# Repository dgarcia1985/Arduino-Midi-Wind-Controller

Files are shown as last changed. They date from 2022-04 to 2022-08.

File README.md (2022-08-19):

# Controlador de viento Midi   
<a href="README.en.md">English</a>   

<a href="https://www.youtube.com/watch?v=sx2wOH4ftkw">Vídeo de demostración</a>   

Aquí está el <a href="Code/midiWindController.ino">código</a> y los recursos para construir un controlador de viento Midi basado en Arduino.   
Mi objetivo era construir un controlador barato con una dinámica mejor que un teclado para tocar trompetas, saxofones, flautas y otros instrumentos de viento.   
He montado el prototipo con piezas impresas en 3D (Los archivos están Disponibles en la carpeta Parts), piezas desmontadas de mandos de videojuegos rotos, cables de distintos dispositivos USB estropeados, sensores y botones.

Las características del instrumento son las siguientes:

* 12 botones para seleccionar que nota se va a tocar, pueden accionarse de forma simultánea.  
* 1 sensor de presión GY-68 BMP180.   
* 1 Joystick de un mando viejo de GameCube para controlar la rueda de Pitch/Modulación.
* 1 potenciómetro lineal del gatillo de un mando de GameCube para controlar el ataque mordiendo la boquilla.
* 8 botones que permiten cambiar configuraciones del dispositivo y calibrarlo.   

Abajo podemos ver el esquema de conexiones del dispositivo:

esquema  

Para poder utilizarlo como un dispositivo MIDI USB normal es necesario reprogramar el firmware de Arduino con <a target="_blank" href="https://github.com/ddiakopoulos/hiduino">Hiduino</a> o similar.   
Para realizar pruebas hasta reprogramar la placa de Arduino como dispositivo MIDI he utilizado <a target="_blank" href="https://projectgus.github.io/hairless-midiserial/">Hairless Midi</a>, ten en cuenta que la tasa de Baudios del dispositivo MIDI es distinta si lo utilizamos con esta aplicación. Se detallará en las instrucciones de montaje.   
Las piezas 3D están modeladas con <a target="_blank" href="https://www.freecadweb.org/">FreeCAD</a>   
Muchas de las piezas utilizadas son demasiado grandes para mi impresora 3D, por lo que algunas piezas han sido impresas partidas en dos para luego unirlas, algunas piezas van atornilladas pero otras han sido unidas utilizando un soldador para fundir el plástico.   
He impreso las piezas en PETG, pero casi todas las piezas deberían poder hacerse en cualquier plástico. La lengüeta que transmite la fuerza de mordida debería estar impresa en un plástico bastante resistente (ABS o PETG).   

Los planos de las piezas los puedes consultar <a href="Plano.pdf">aquí</a>.

También tienes disponibles <a href="Parts/Stl">las Piezas para imprimir en formato stl</a> y <a href="Parts/FreeCAD">las piezas modeladas en FreeCAD por si quieres realizar alguna modificación.</a>   

La lista completa de componentes es la siguiente:

* Placa Arduino Uno o compatible (Asegurate de que puede reprogramarse o sólo lo podrás usar mediante un programa Serial a Midi).   
* 12 Botones de interruptor para Arduino.   
* 1 Joystick (Sólo utilizaremos un eje así que puede valer cualquier potenciómetro rotatorio con un sistema de retorno a la posición central).   
* 1 potenciómetro deslizante (Utilice el de el gatillo de un mando de GameCube, pero se estropeó y lo cambié por uno A20K que es lo que encontré que me entrará en la pieza que ya tenía diseñada) que recibirá la fuerza de la mordida.
* 1 Muelle para crear el efecto de autoretorno en el potenciómetro deslizante (También utilice uno de un mando de GameCube roto).
* 4 resistencias de 1k, 2 de 2k, 2 de 5.1k y 2 de 10k. Los valores en realidad pueden ser distintos. En la wiki con las instrucciones de montaje hay más información sobre lo que hacen.   
* 1 sensor GY-68 BMP180.
* Conectores JST para organizar los cables de manera más sencilla.
* Las Piezas impresas en 3D de arriba.

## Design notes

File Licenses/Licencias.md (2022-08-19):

# Licencias

Este repositorio no distribuye código de terceros aunque para compilarlo tendrás que descargar del gestor de librerías de Arduino IDE las siguientes librerías:

* [MIDI Library](https://www.arduino.cc/reference/en/libraries/midi-library/)
* [Adafruit Bmp 085](https://www.arduino.cc/reference/en/libraries/adafruit-bmp085-library/)

# Imágenes

Para las instrucciones de la wiki he sacado imágenes de las siguientes fuentes:
* [Placa Arduino UNO](https://commons.wikimedia.org/wiki/File:ArduinoUno.svg)
* [Botones (Están modificados)](https://elements.wokwi.com/?path=/story/pushbutton--red)
* [Resistencias](https://elements.wokwi.com/?path=/story/resistor--1%CF%89)
* [Joystick](https://elements.wokwi.com/?path=/story/analog-joystick--joystick)
* [Potenciómetro deslizante](https://elements.wokwi.com/?path=/story/slide-potentiometer--default)

# Software utilizado

Para realizar tanto el proyecto como la documentación he usado los siguientes programas:

* [Arduino IDE](https://www.arduino.cc/en/software) 
* [FreeCAD para el modelado de piezas y los planos](https://www.freecad.org/downloads.php)
* [Blender para los vídeos de montaje e imágenes de la documentación](https://www.blender.org/)
* [Inkscape para los dibujos de la documentación](https://inkscape.org/es/)
* [QSynth para probar el instrumento en vídeos de prueba](https://qsynth.sourceforge.io/)

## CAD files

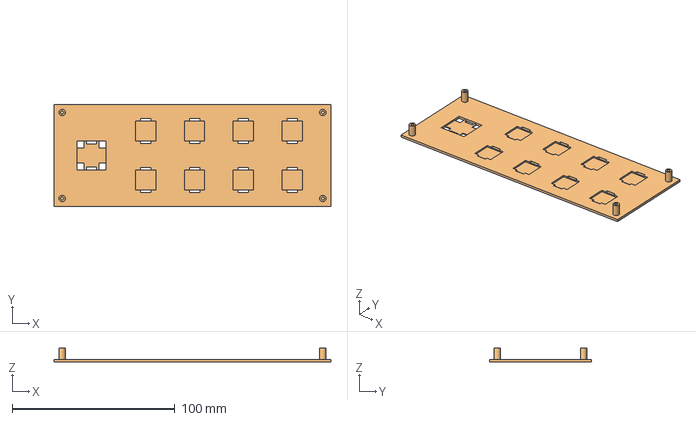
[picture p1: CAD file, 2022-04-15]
Parts/FreeCAD/soporte botones atras.FCStd
170.0 x 62.8 x 8.50 mm

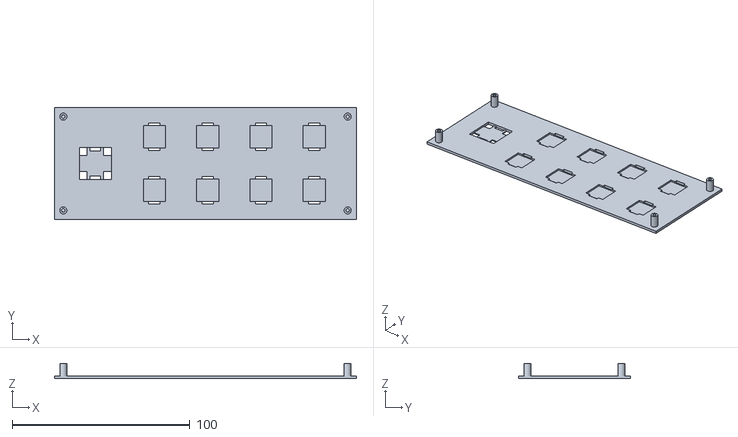
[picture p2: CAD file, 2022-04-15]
Parts/Stl/04 - Soporte de botones trasero.stl
170.0 x 62.8 x 8.50

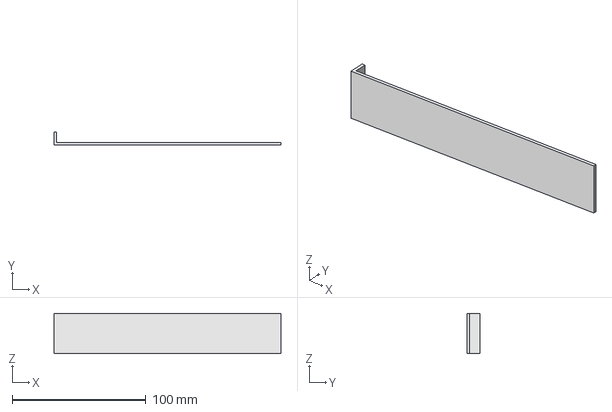
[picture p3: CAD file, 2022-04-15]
Parts/FreeCAD/tapa lados.FCStd
170.0 x 10.0 x 30.0 mm

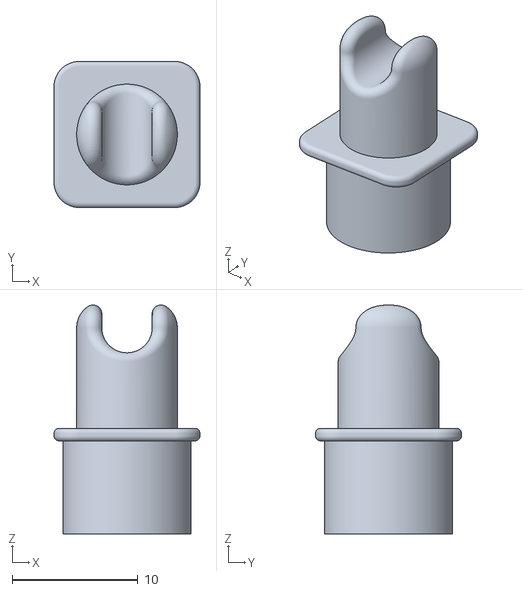
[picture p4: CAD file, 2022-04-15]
Parts/Stl/20 - Tapa potenciometro.stl
11.6 x 11.6 x 18.2

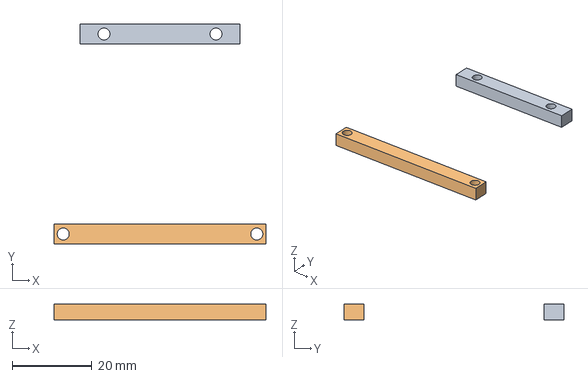
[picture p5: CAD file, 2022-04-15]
Parts/FreeCAD/Soportes tornillos.FCStd
53.0 x 55.0 x 4.00 mm
soporte tornillos arduino 1_Body_001
soporte tornillos arduino 2_Body_001

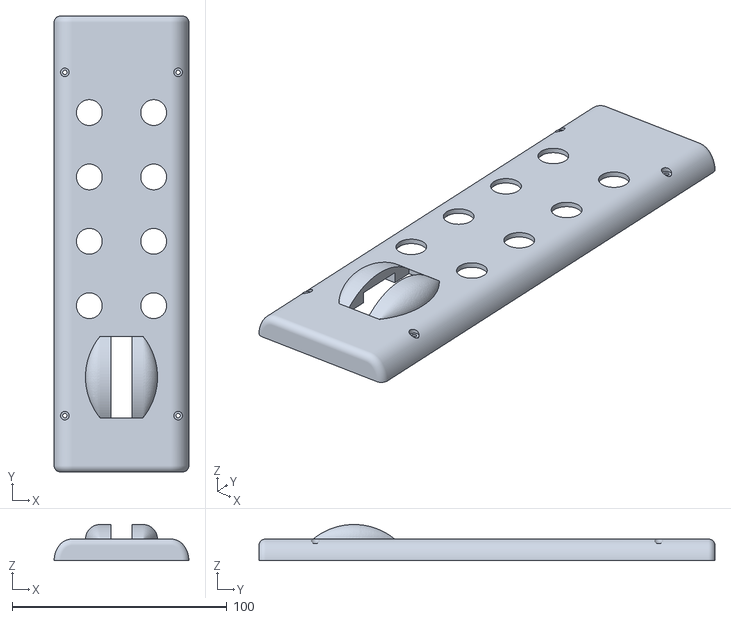
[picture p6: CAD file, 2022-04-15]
Parts/Stl/01 - Cubierta Trasera.stl
62.8 x 212.5 x 16.8

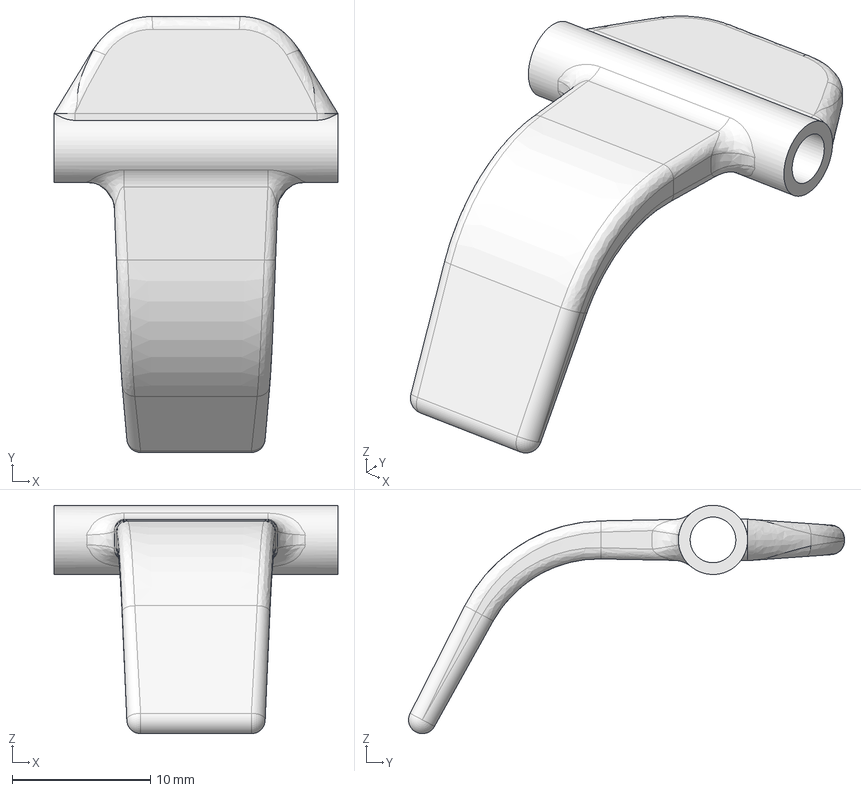
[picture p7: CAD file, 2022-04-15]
Parts/FreeCAD/lengueta.FCStd
20.5 x 31.5 x 16.5 mm

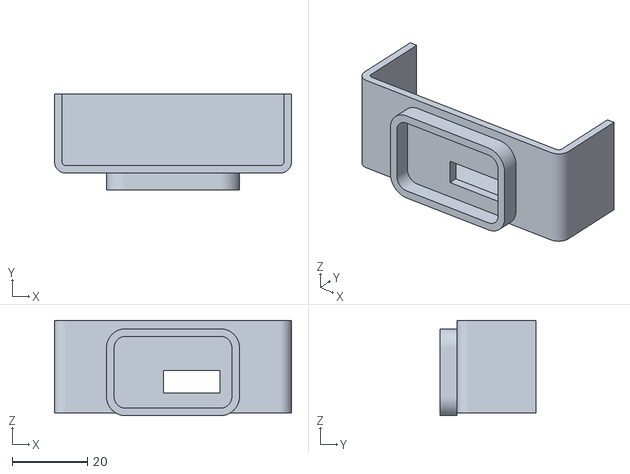
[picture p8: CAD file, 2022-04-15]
Parts/Stl/06 - Enganche Boquilla.stl
62.8 x 25.5 x 25.2

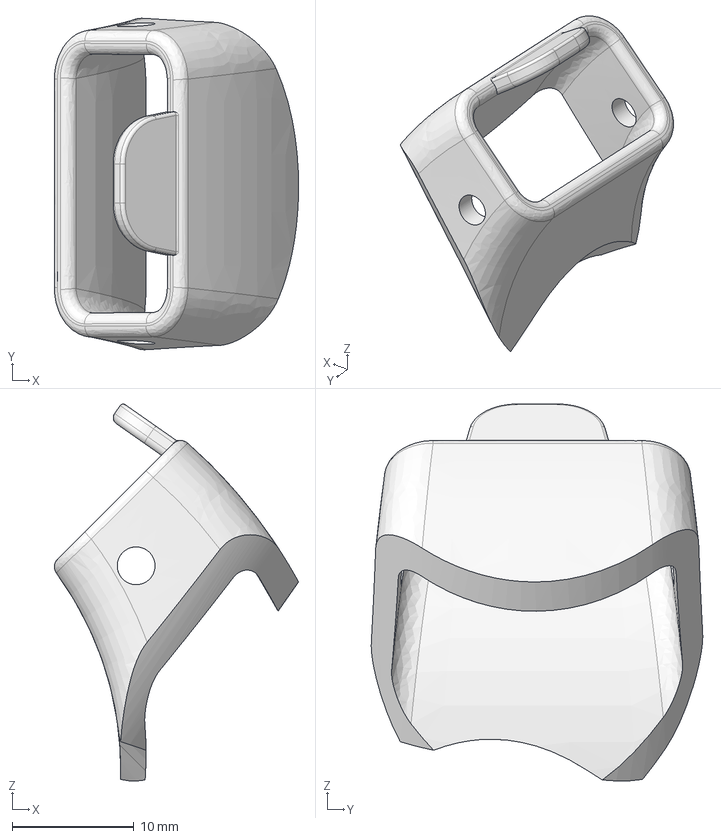
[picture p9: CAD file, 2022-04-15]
Parts/FreeCAD/boquilla.FCStd
20.0 x 27.2 x 30.9 mm

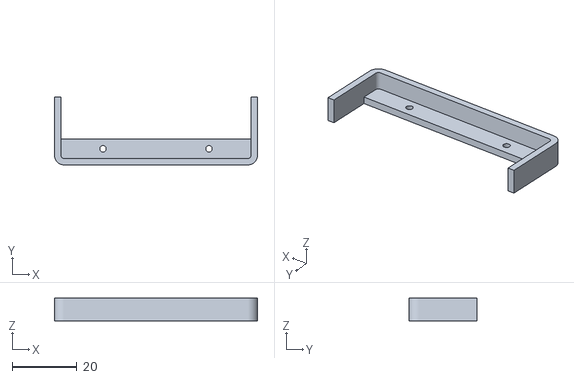
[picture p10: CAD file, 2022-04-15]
Parts/Stl/11 - Tapas.stl
62.8 x 21.0 x 7.00

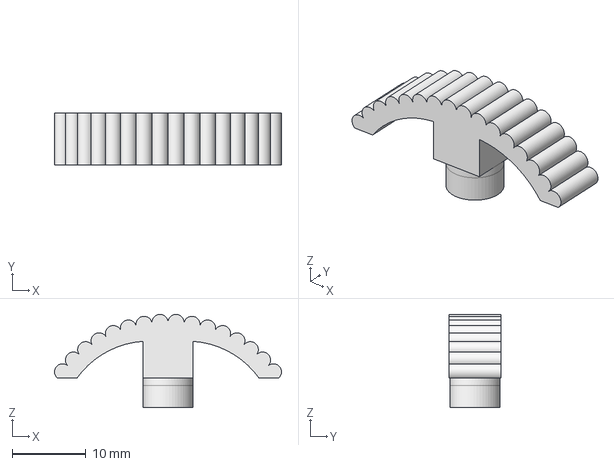
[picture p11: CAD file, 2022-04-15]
Parts/FreeCAD/rueda pitch.FCStd
30.8 x 7.00 x 12.7 mm

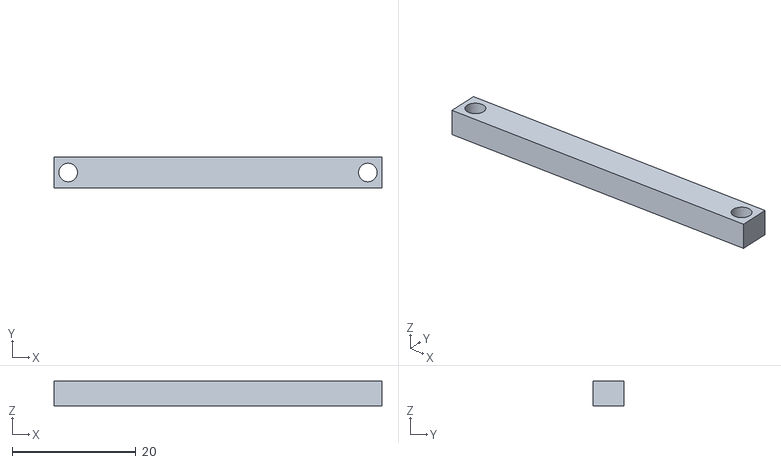
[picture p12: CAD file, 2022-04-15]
Parts/Stl/09 - Soporte tornillos arduino 2.stl
53.0 x 5.00 x 4.00

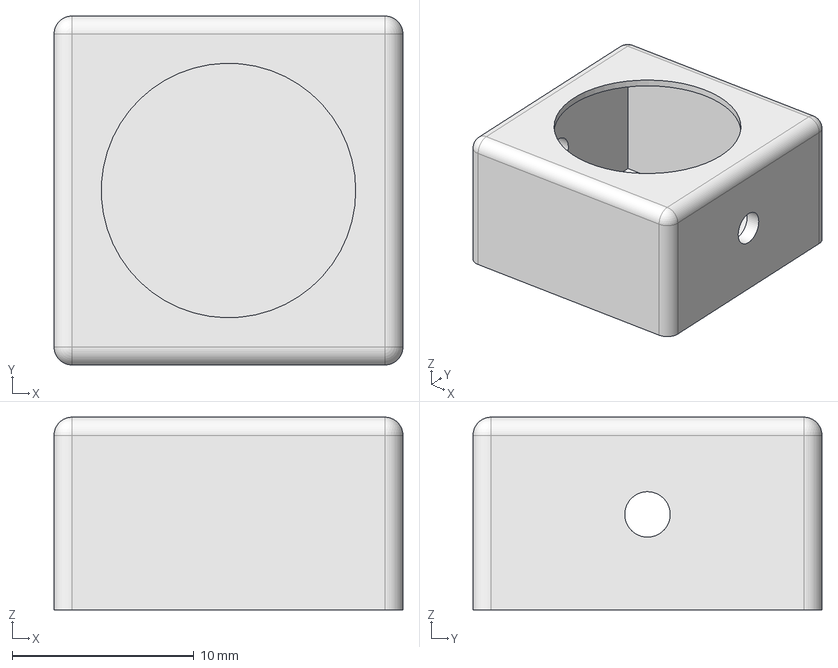
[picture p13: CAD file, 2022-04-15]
Parts/FreeCAD/Base Joystick.FCStd
19.2 x 19.2 x 10.6 mm

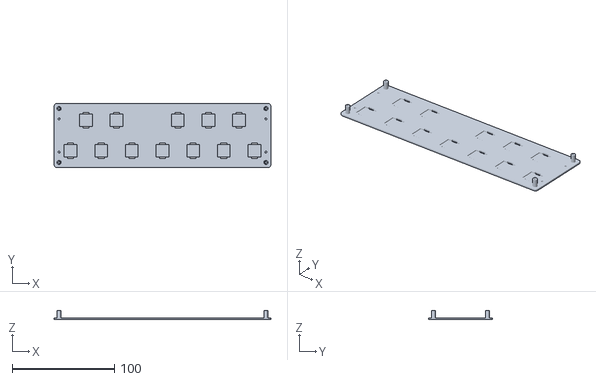
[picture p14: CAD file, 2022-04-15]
Parts/Stl/21 - Soporte botones arriba.stl
212.5 x 62.8 x 8.50

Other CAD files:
Parts/FreeCAD/Potenciometro.FCStd
Parts/Stl/14 - Lengueta.stl
Parts/FreeCAD/tapas.FCStd
Parts/Stl/05 - Rueda pitch.stl
Parts/FreeCAD/Arduino Uno.FCStd
Parts/FreeCAD/Base boton.FCStd
Parts/FreeCAD/Eje Joystick.FCStd
Parts/FreeCAD/Muelle.FCStd
Parts/FreeCAD/Pulsador Boton.FCStd
Parts/FreeCAD/carcasa arduino.FCStd
Parts/FreeCAD/carcasa pot linear.FCStd
Parts/FreeCAD/cubierta trasera.FCStd
Parts/FreeCAD/cubierta.FCStd
Parts/FreeCAD/eje.FCStd
Parts/FreeCAD/enganche boquilla.FCStd
Parts/FreeCAD/placa resistencias.FCStd
Parts/FreeCAD/soporte botones.FCStd
Parts/FreeCAD/soporte tornillos arduino 1.FCStd
Parts/FreeCAD/soporte tornillos arduino 2.FCStd
Parts/FreeCAD/tapa pot linear.FCStd
Parts/Stl/07 - Carcasa para Arduino.stl
Parts/Stl/08 - Soporte tornillos arduino 1.stl
Parts/Stl/12 - Tapa Lados.stl
Parts/Stl/13 - Boquilla.stl
Parts/Stl/17 - Carcasa Potenciometro.stl
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

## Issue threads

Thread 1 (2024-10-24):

Contacto

habuenav, 2024-10-24:
Hola, discúlpame que te contacte por acá, solo que veo que te interesan este tipo de proyectos y yo actualmente estoy  trabajando también en un EWI, lo mio es mas la programación que el diseño 3D y electrónico, entonces como necesito un poco de ayuda con ese tema, quería saber cuanto me cobrarías por ayudarme a diseñar la carcasa para mi proyecto, actualmente ya tengo un boceto muy básico hecho con tinkercad pero quisiera algo mejor y quizás tu puedas ayudarme con ese tema ya que veo que te interesan este tipo de proyectos, te comparto la presentación de mi proyecto en un grupo de makers https://www.youtube.com/watch?v=MsFFuOXiIuM&t=1822s  de antemano gracias por la atención prestada y muy buen trabajo con tu proyecto.

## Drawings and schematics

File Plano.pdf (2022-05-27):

# ControladordeViento MidiBasado en Arduino

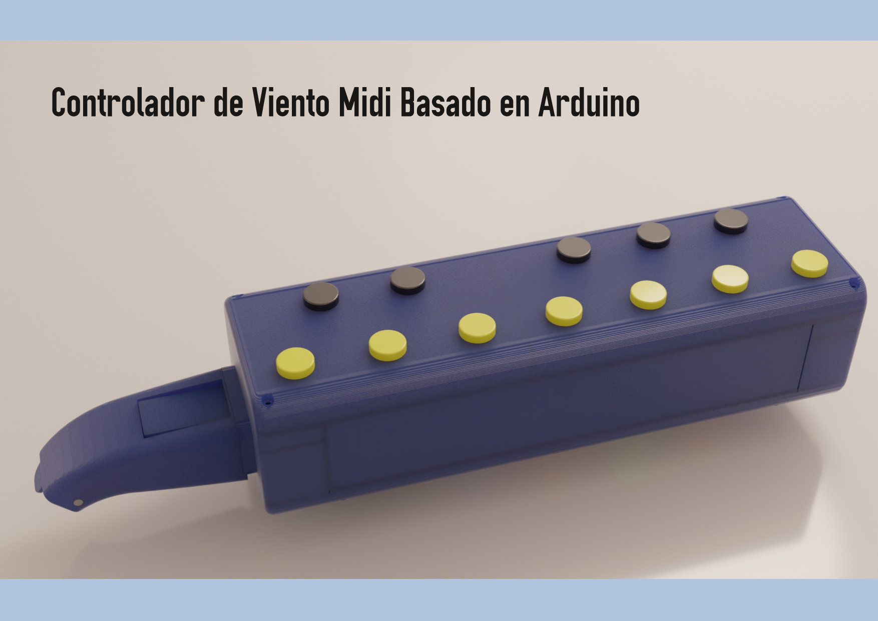
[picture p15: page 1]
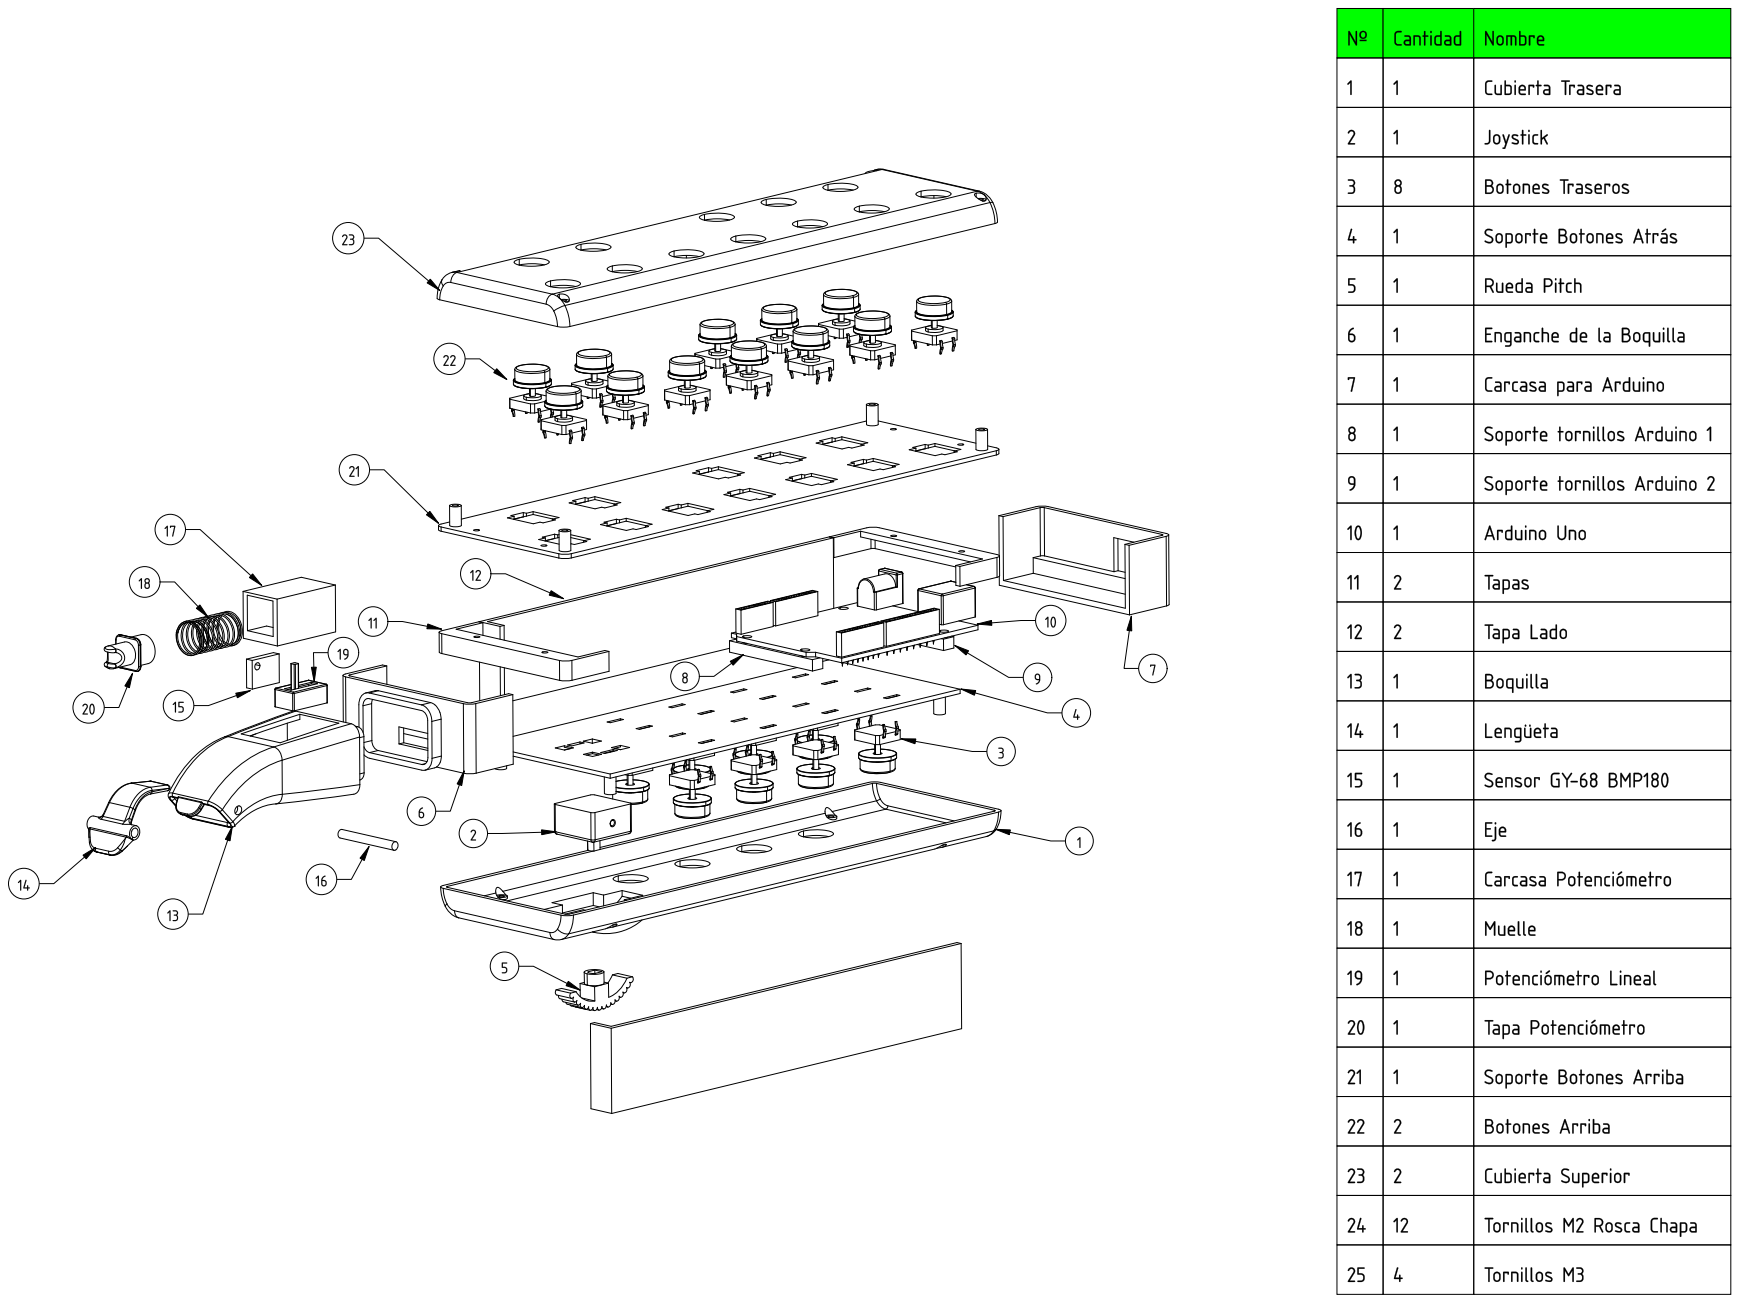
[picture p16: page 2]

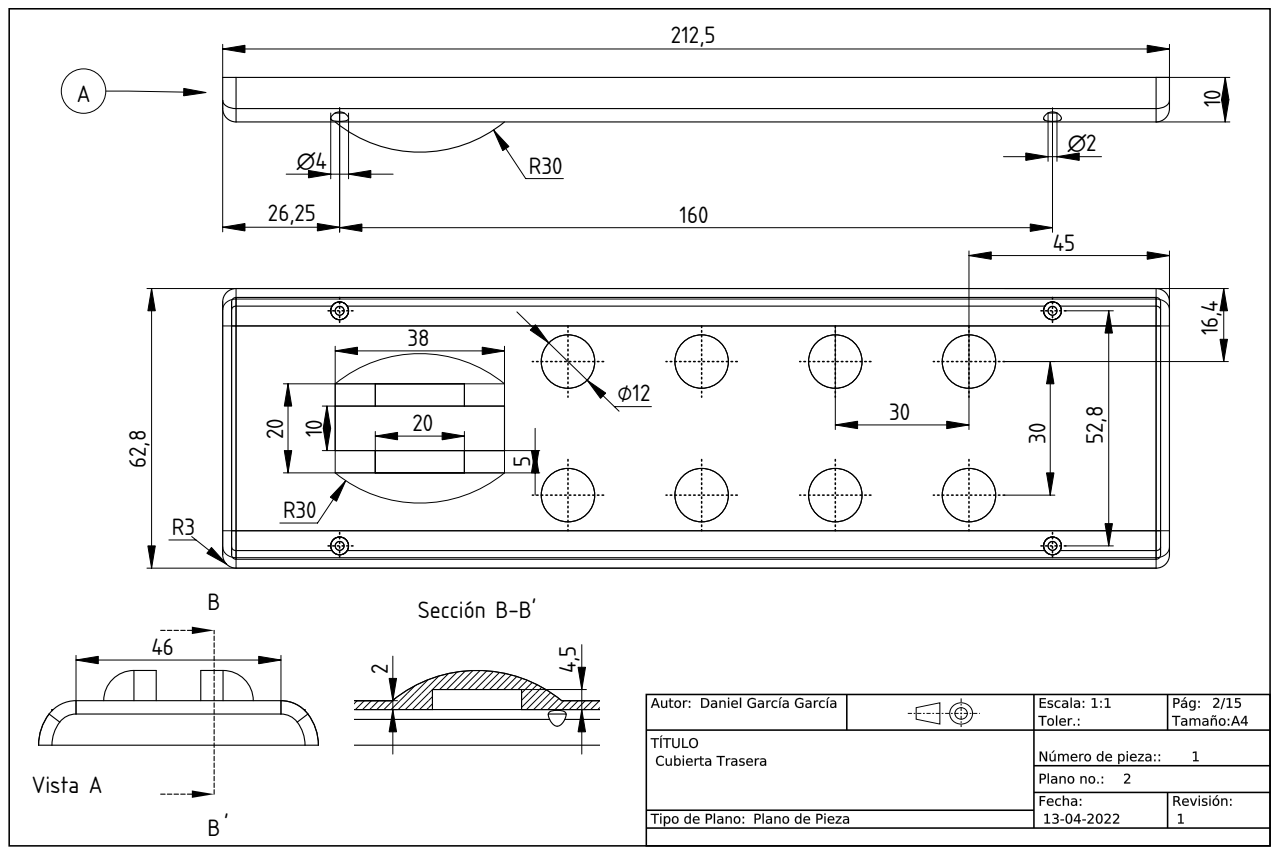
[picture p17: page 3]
Vista; ecció

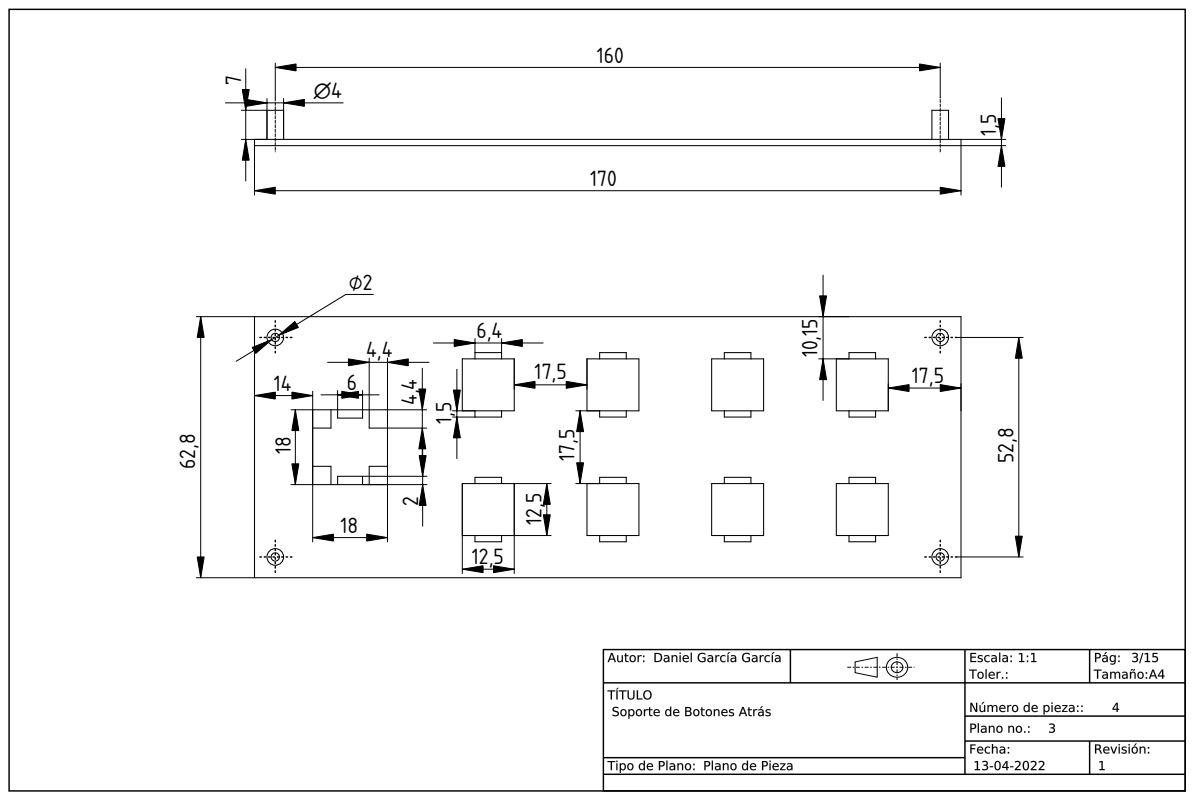
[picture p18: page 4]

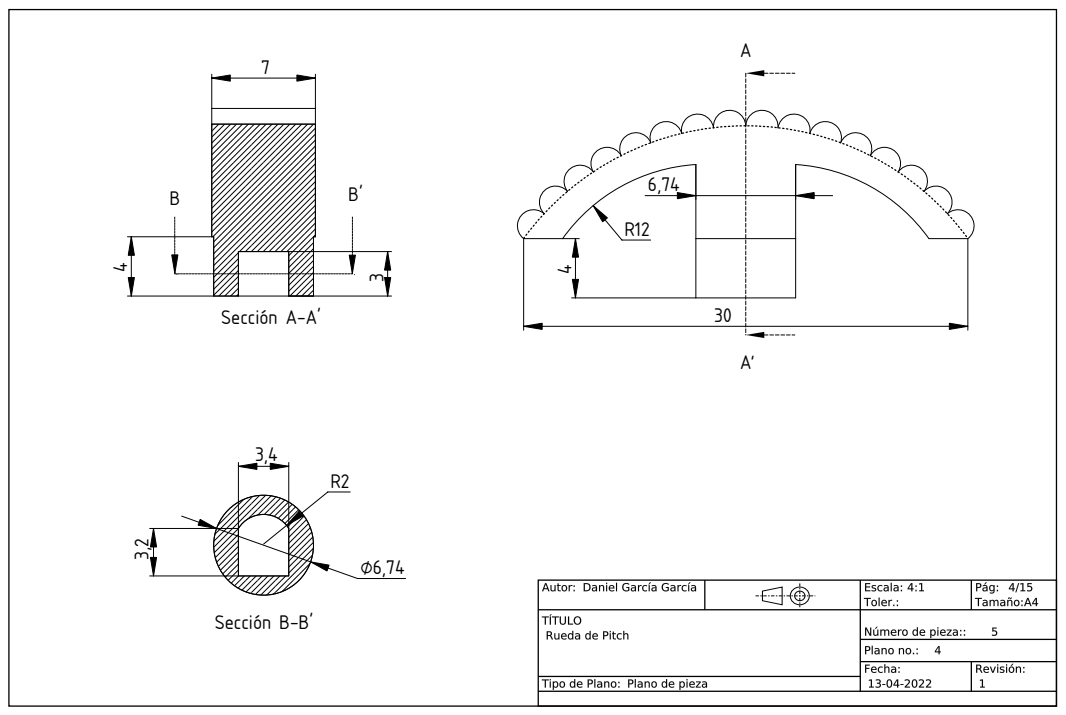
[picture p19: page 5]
Sección A-A'; Sección B-B'

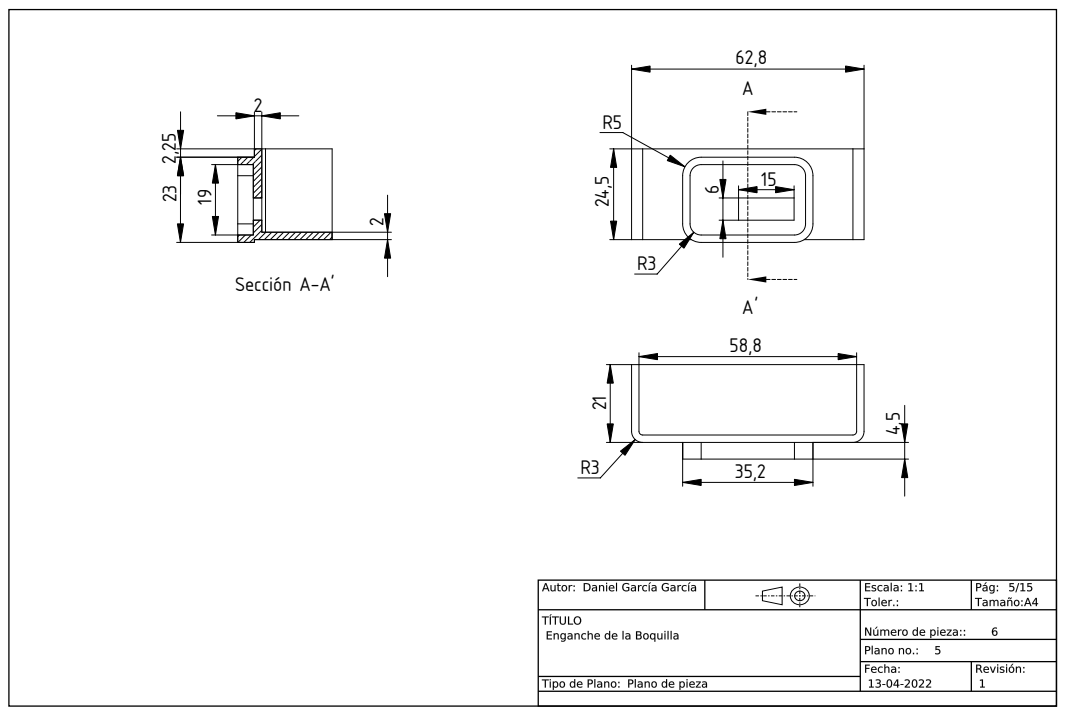
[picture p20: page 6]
ecció

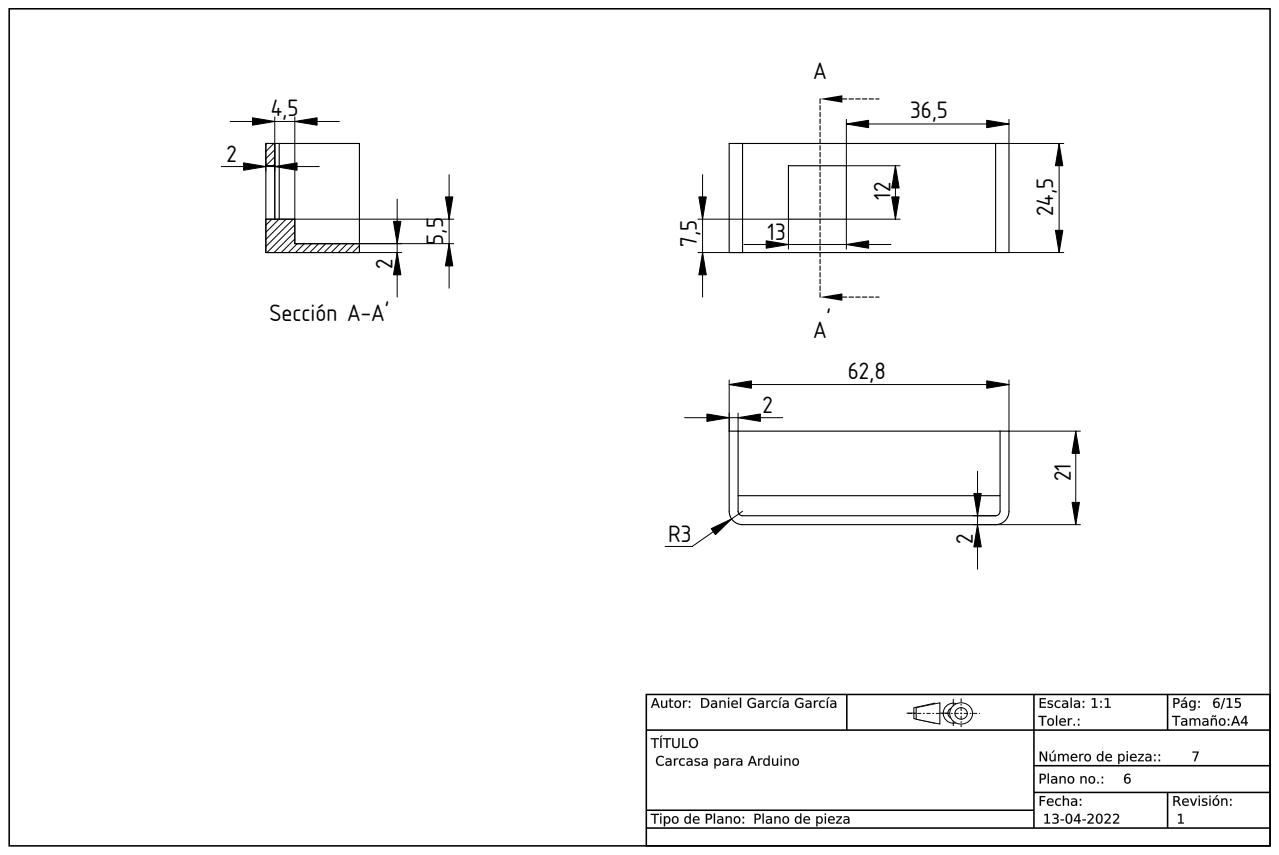
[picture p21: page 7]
ecció

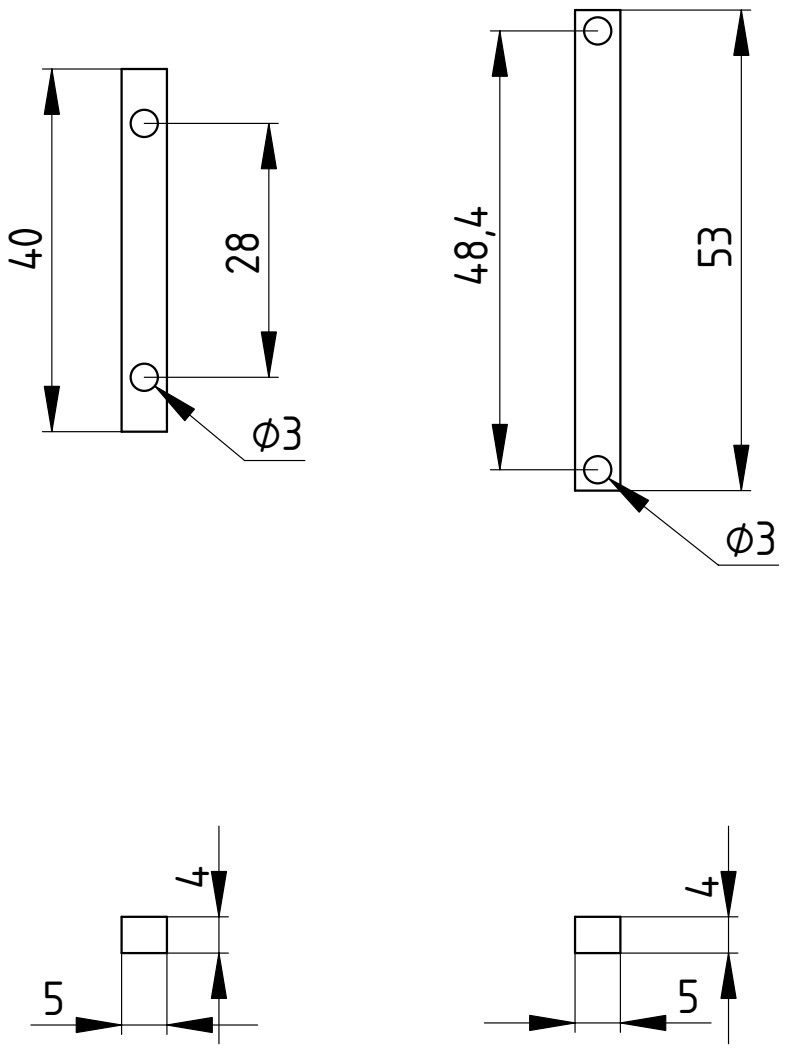
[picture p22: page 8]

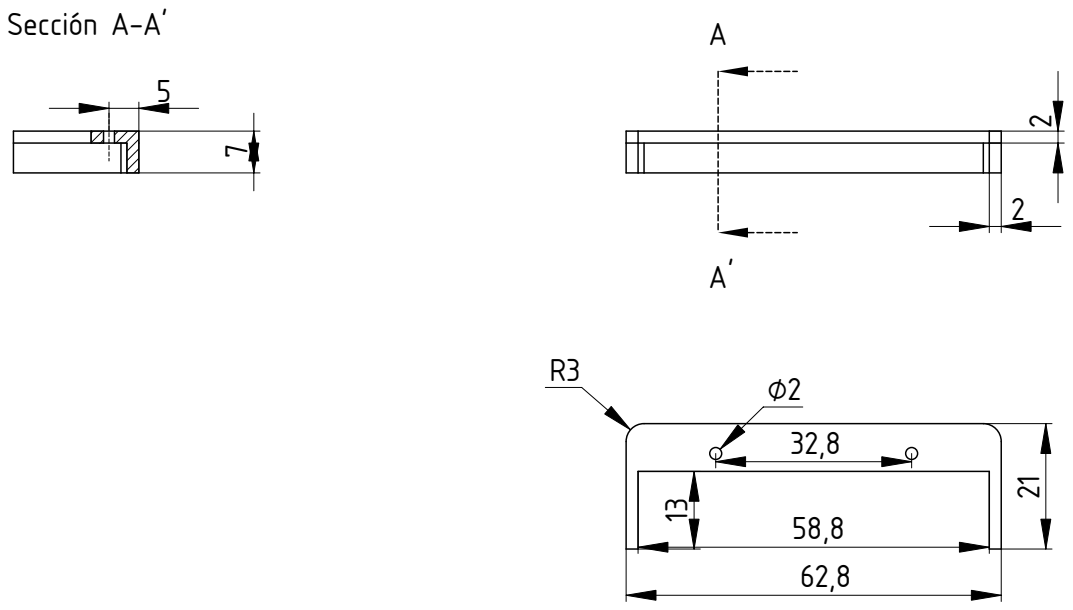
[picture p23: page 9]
ecció

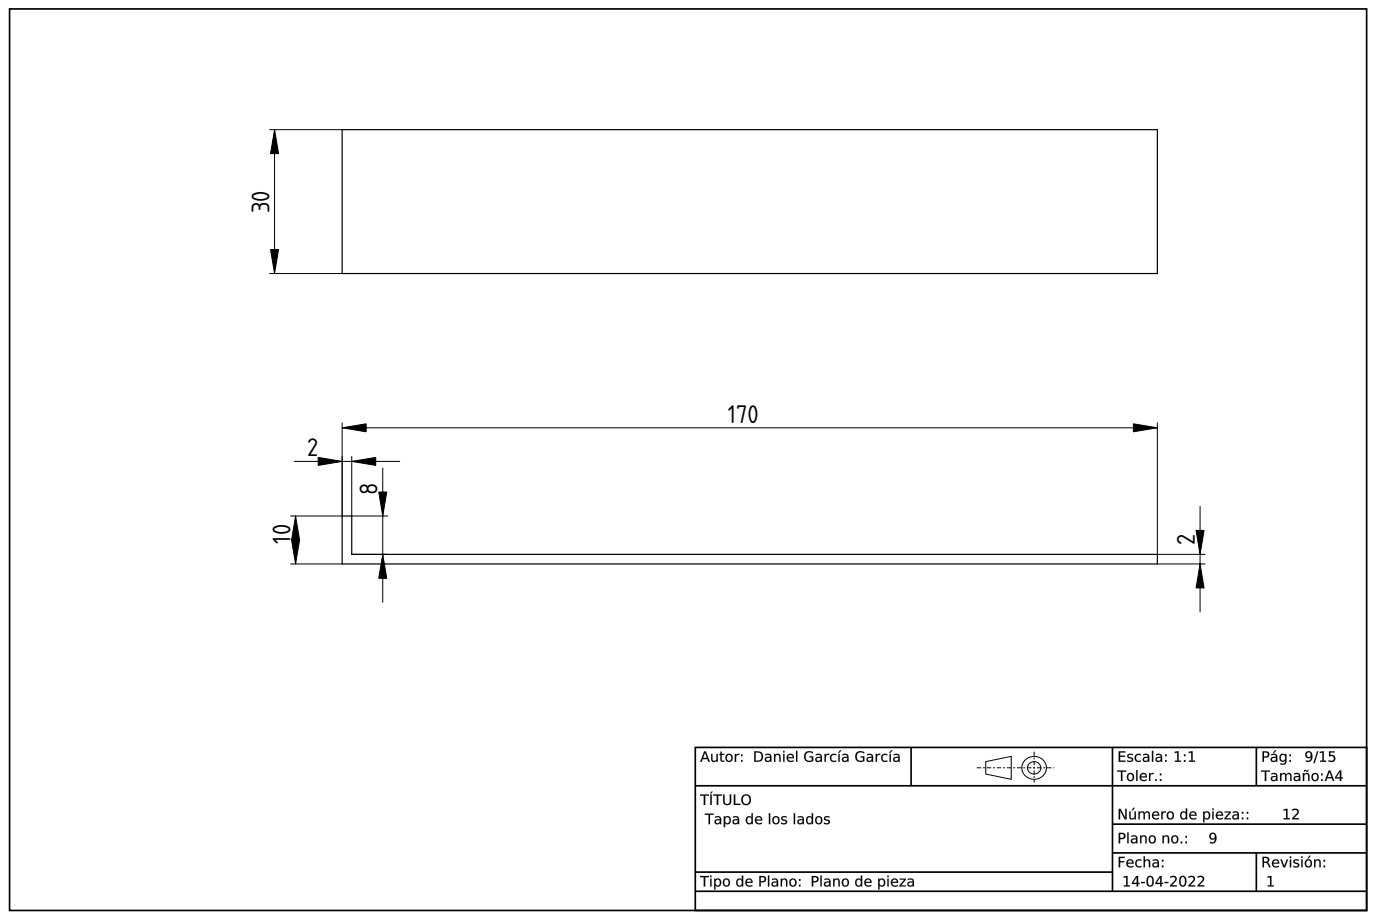
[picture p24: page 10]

3,1 R

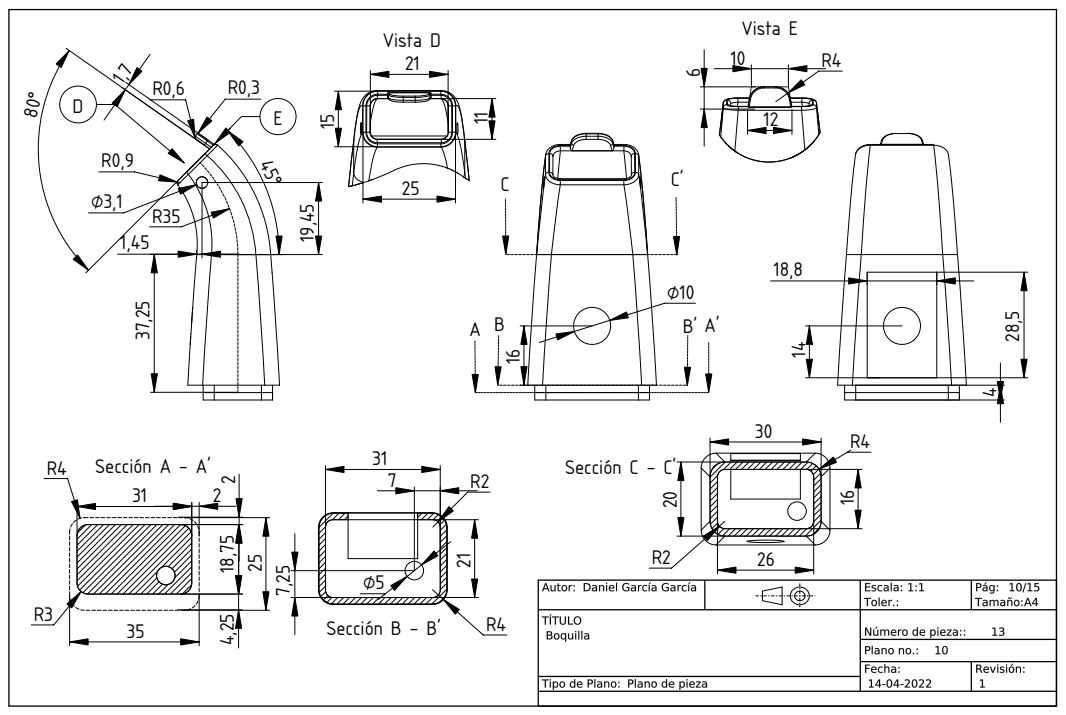
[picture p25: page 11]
ecció; C' Sección C - C' 25; Vista

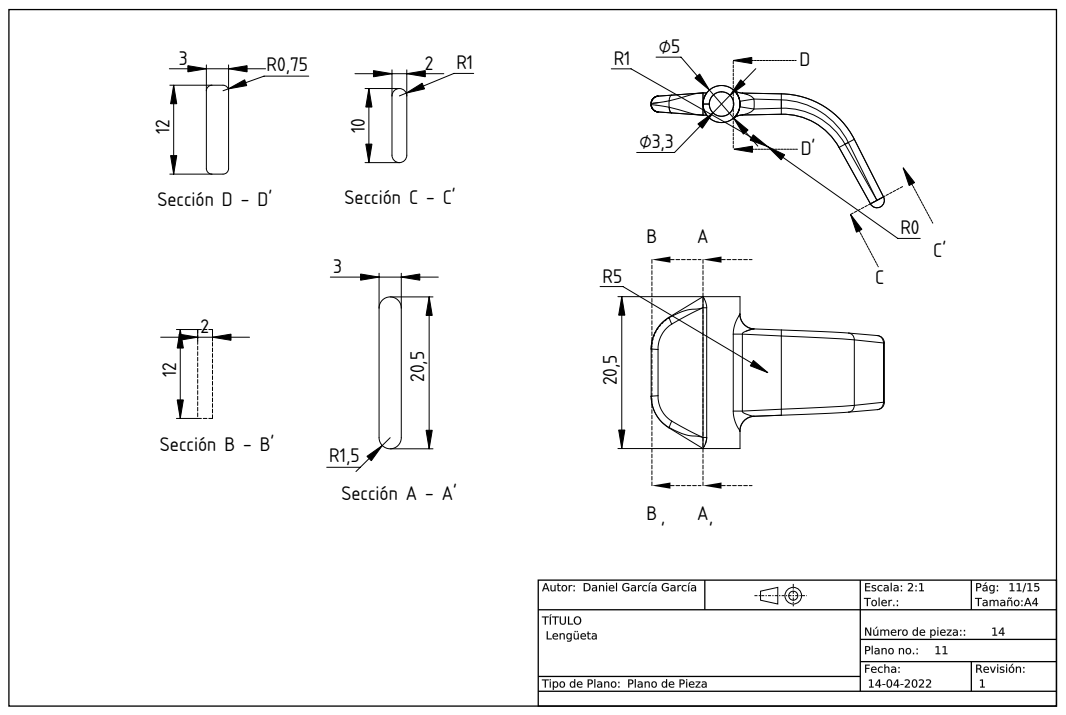
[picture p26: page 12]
ecció; R1 Sección D - D'; Sección C - C'


0,7 6

ecció


Sección A-A' Escala 1:2; Sección B - B'

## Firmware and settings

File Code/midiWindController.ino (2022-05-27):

#include <MIDI.h>
#include <Adafruit_BMP085.h>
MIDI_CREATE_DEFAULT_INSTANCE();

unsigned long t1,t2;
bool b11, b12, b13, b14,b21,b22,b23,b24;
bool s11, s12, s13, s14,s21,s22,s23,s24,s112,s212,s221;
int botonera;
long mordida;
int mordidamax;
int mordidabase;
byte prevMordida;
byte transpose;
byte ntranspose;
bool notas[12];
bool notasOn[127];
byte canal;
long prevPitch;
long pitch;
long presionbase;
long presionmax;
long presion;
int umbral=10;
bool sonando;
byte programa;
bool rueda;

Adafruit_BMP085 bmp;

void setup()
{
  // put your setup code here, to run once:


 if (!bmp.begin()) {
  Serial.println("No se puede iniciar el sensor de presión");
  while (1) {}
  }
 MIDI.begin(1);

  mordidamax=500;
  mordidabase=325;
  presionmax=97360;

  presionbase=bmp.readPressure();
  presionmax=presionmax-presionbase;
  t1=0;
  for (byte a=2; a<=13;a++)
  {
  pinMode(a,INPUT_PULLUP);
  }
  canal=1;
  sonando=0;
  transpose=5;
  ntranspose=11;
}
void loop()
{
//almacena las notas que están pulsadas.

for (int a=0; a<12;a++)
{
  notas[a]=!digitalRead(a+2);
}
//Comprueba el estado de la botonera 1
botonera=analogRead(1);
 
if (botonera<=368)
{
  b11=true;
  b12=true;
  b13=true;
  b14=true;
}
else if (botonera<=514)
{
b11=true;
  if (botonera<=411)
  {
  b12=true;
    if (botonera<=381)
    {
    b13=true;
    }
    else if (botonera<=395)
    {
    b14=true;
        b13=false;
    }
        else
        {
        b13=false;
      b14=false;
        }
  }
  else if (botonera<=468)
  {
  b13=true;
    b12=false;
    if (botonera<=448)
    {
    b14=true;
    }
        else
        {
        b14=false; 
        }
  }
  else if (botonera<=489)
  {
  b14=true; 
    b12=false;
    b13=false;
  }
    else
    { 
    b12=false;
    b13=false;
    b14=false;
    }
}
else if (botonera<=684)
{
  b12=true;
    b11=false;
  if (botonera<=605)
  {
  b13=true;
    if (botonera<=572)
    {
    b14=true;
    }
        else
        {
        b14=false;
        }
  }
  else if (botonera<=641)
  {
  b14=true;
    b13=false;
  }
    else
    {
    b13=false;
    b14=false;
    }
}
else if (botonera<=857)
{
  b13=true;
    b11=false;
    b12=false;
  if (botonera<=791)
  {
  b14=true;
  }
    else
    {
    b14=false;
    }

}
else if (botonera<=932)
{
  b14=true;
    b11=false;
    b12=false;
    b13=false;
  
}
else
{
    b11=false;
    b12=false;
    b13=false;
    b14=false;
}

//Comprueaba el estado de la botonera 2
botonera=analogRead(2);

if (botonera<=368)
{
  b21=true;
  b22=true;
  b23=true;
  b24=true;
}
else if (botonera<=514)
{
b21=true;
  if (botonera<=411)
  {
  b22=true;
    if (botonera<=381)
    {
    b23=true;
    }
    else if (botonera<=395)
    {
    b24=true;
        b23=false;
    }
        else
        {
        b23=false;
      b24=false;
        }
  }
  else if (botonera<=468)
  {
  b23=true;
    b22=false;
    if (botonera<=448)
    {
    b24=true;
    }
        else
        {
        b24=false; 
        }
  }
  else if (botonera<=491)
  {
  b24=true; 
    b22=false;
    b23=false;
  }
    else
    { 
    b22=false;
    b23=false;
    b24=false;
    }
}
else if (botonera<=684)
{
  b22=true;
    b21=false;
  if (botonera<=605)
  {
  b23=true;
    if (botonera<=572)
    {
    b24=true;
    }
        else
        {
        b24=false;
        }
  }
  else if (botonera<=641)
  {
  b24=true;
    b23=false;
  }
    else
    {
    b23=false;
    b24=false;
    }
}
else if (botonera<=857)
{
  b23=true;
    b21=false;
    b22=false;
  if (botonera<=791)
  {
  b24=true;
  }
    else
    {
    b24=false;
    }

}
else if (botonera<=932)
{
  b24=true;
    b21=false;
    b22=false;
    b23=false;
  
}
else
{
    b21=false;
    b22=false;
    b23=false;
    b24=false;
}

//calcula y envía el pitch bend y la modulacion en funcion del modo de rueda


  pitch=analogRead(0)-525;
  if (pitch<-512)
  {
  pitch=-512;
  }
  if (pitch>0)
  {
  pitch=(pitch*512)/498;
  }
  pitch=16*pitch;
  if (pitch>8191)
  {
  pitch=8191; 
  }
  
 if (abs(pitch-prevPitch)>16)
 {
  prevPitch=pitch;
    if ((b24==0 && rueda==0) || (rueda==1 && (b23==1 || b24==1)))
    {
   MIDI.sendPitchBend(int(pitch),canal);
    }
    if ((rueda==0 && (b24==1 || b23==1)) || (b23==0 && rueda==1) )
    {
   MIDI.sendControlChange(1,abs(pitch/64),canal);
    }
 }
  
 
// Calcula y envía los datos de mordida

mordida=analogRead(3)-mordidabase;
if (mordida<0)
{
  mordida=0;
}
mordida=(mordida*127)/(mordidamax-mordidabase);
if (mordida>127)
{
    mordida=127;
}

if (abs(mordida-prevMordida)>5)
{

  prevMordida=mordida;
 MIDI.sendControlChange(73,mordida,canal);
 MIDI.sendControlChange(1,mordida/2,canal);

}

//Controlar transposición de octavas y notas 
if (b11==1)
{

    if (b14==1 && s14==0 && s112==0)
    {
      s14=1;
      if (transpose<10)
      {
      transpose++;
      }
    }
    if (b13==1 && s13==0 && s112==0)
    {
      s13=1;
      if (transpose>0)
      {
      transpose--;
      }
    }
    if (b24==1 && s24==0 && s112==0)
    {
      s24=1;
      if (ntranspose<22)
      {
      ntranspose++;
      }
      else
      {
              if (transpose<10)
              {
              ntranspose=11;
              transpose++;
              }
      }

      
    }
    if (b23==1 && s23==0 && s112==0)
    {
      s23=1;
      if (ntranspose>0)
      {
      ntranspose--;
      }
      else
      {
              if (transpose>0)
               {
               ntranspose=11;
               transpose--;
               }
      }     
    }
    if (b12==0)
    {
    s11=1;
    }
  if (b12==1 && s11==1 && s12==0)
  {
    s112=1;   
  }
  if (s112==1 && b14==1 && s14==0)
  {
     programa=programa+10;
     if (programa>127)
     {
      programa=127;
     }
      MIDI.sendProgramChange(programa,canal);
    s14=1;
  }
  if (s112==1 && b13==1 && s13==0)
  {
     if (programa>10)
     {
      programa-=10;
     }
     else
     {
      programa=0;
     }
      MIDI.sendProgramChange(programa,canal);
    s13=1;    
  }
  if (s112==1 && b24==1 && s24==0)
  {

     programa++;
         Serial.println(programa);
     if (programa>127)
     {
      programa=127;
     }
      MIDI.sendProgramChange(programa,canal);
    s24=1;
  }
 if (s112==1 && b23==1 && s23==0)
  {
     if (programa>0)
     {
      programa--;
     }
      MIDI.sendProgramChange(programa,canal);
    s23=1;    
  }
   if (s112==1 && b22==1 && s22==0)
  {
     if (canal<16)
     {
       for (byte a=0; a<12;a++)
        {
        notasOn[((transpose*12)+(ntranspose-11)+a)]=0;
      MIDI.sendNoteOff(((transpose*12)+(ntranspose-11)+a),0,canal);
        }
      canal++;
     }
  
    s22=1;    
  }
     if (s112==1 && b21==1 && s21==0)
  {
     if (canal>1)
     {
       for (byte a=0; a<12;a++)
        {
        notasOn[((transpose*12)+(ntranspose-11)+a)]=0;
      MIDI.sendNoteOff(((transpose*12)+(ntranspose-11)+a),0,canal);
        }
      canal--;
     }
  
    s21=1;    
  }
  

}
else
{
    if (b14==1 && s14==0)
    {
      if (transpose<10)
      {
        for (byte a=0; a<12;a++)
        {
        notasOn[((transpose*12)+(ntranspose-11)+a)]=0;
      MIDI.sendNoteOff(((transpose*12)+(ntranspose-11)+a),0,canal);
        }
        transpose++;
      }
      s14=1;
    }
    if (b14==0 && s14==1)
    {

      if (transpose>0)
      {
        for (byte a=0; a<12;a++)
        {
        notasOn[((transpose*12)+(ntranspose-11)+a)]=0;
      MIDI.sendNoteOff(((transpose*12)+(ntranspose-11)+a),0,canal);
        }
        transpose--;
      }

    }
    if (b13==1 && s13==0)
    {
      if (transpose>0)
      {
        for (byte a=0; a<12;a++)
        {
        notasOn[((transpose*12)+(ntranspose-11)+a)]=0;
      MIDI.sendNoteOff(((transpose*12)+(ntranspose-11)+a),0,canal);
        }
        transpose--;
      }
      s13=1;
    }
        if (b13==0 && s13==1)
    {
      
      if (transpose<10)
      {
        for (byte a=0; a<12;a++)
         {
        notasOn[((transpose*12)+(ntranspose-11)+a)]=0;
      MIDI.sendNoteOff(((transpose*12)+(ntranspose-11)+a),0,canal);
         }
        transpose++;
      }
    }

}

if (b21==1 && s21==0 && s22==0)
{
    s21=1;

}
if (b22==1 && s21==1 && s22==0)
{
  s22=1;
  s212=1;
   presionbase=bmp.readPressure();
}

if (b22==1 && s22==0 && s21==0)
{
    s22=1;
    
}
if (b21==1 && s22==1 && s21==0)
{
  s21=1;
  s221=1;
  mordidabase=analogRead(3);
}

if (s212==1)
{
 presionmax=bmp.readPressure()-presionbase;
}

if (s221==1)
{
  mordidamax=analogRead(3);
}

if (b12==1 && s12==0 && s112==0)
{
  rueda=!rueda;
  s12=1;
}

if (b11==0)
{
  s11=0;
  s112=0;
}
if (b12==0 && s112==0)
{
  s12=0;
  s112=0;
}
if (b13==0)
{
  s13=0;
}
if (b14==0)
{
  s14=0;
}
if (b23==0)
{
  s23=0;
}
if (b24==0)
{
  s24=0;
}
if (b21==0)
{
  s21=0;
  s212=0;
  s221=0;
}
if (b22==0)
{
  s22=0;
  s212=0;
  s221=0;
}

presion=bmp.readPressure()-presionbase;
presion=(presion*127)/presionmax;
if (presion<0)
{
  presion=0;
}
if (presion>127)
{
  presion=127;
}


//lee el sensor de presión y envía las notas
if ((presion>=umbral))
{ 
  sonando=1;
  for (int a=0; a<12; a++)
  {
    if (notasOn[((transpose*12)+(ntranspose-11)+a)]==0 && notas[a]==1)
   { 
   MIDI.sendNoteOn(((transpose*12)+(ntranspose-11)+a),127,canal);

    notasOn[((transpose*12)+(ntranspose-11)+a)]=1;
   }
 //  MIDI.sendControlChange(64,127,canal); 
   MIDI.sendControlChange(7,presion,canal);
  }
}
else if (presion<umbral && sonando==1)
{
    MIDI.sendControlChange(64,0,canal); 
  for (int a=0; a<12; a++)
  {

    if (notasOn[((transpose*12)+(ntranspose-11)+a)])
    {
    MIDI.sendNoteOff(((transpose*12)+(ntranspose-11)+a),0,canal);
    
    notasOn[((transpose*12)+(ntranspose-11)+a)]=0;
    }
  }
 sonando=0;
}

for (byte a=0; a<12; a++)
{
  
if (notas[a]==0 && notasOn[((transpose*12)+(ntranspose-11)+a)]==1)
  {
    notasOn[((transpose*12)+(ntranspose-11)+a)]=0;
   MIDI.sendNoteOff(((transpose*12)+(ntranspose-11)+a),0,canal);
  }
}
}

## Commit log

2022-04-15 Añadir Carpeta con las Partes
    [01 - Cubierta Trasera.stl, 04 - Soporte de botones trasero.stl, 05 - Rueda pitch.stl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]
2022-04-17 Reorganización de la documentación
2022-04-17 Traducción de la documentación
2022-04-19 Añadir vídeo de demostración
2022-05-27 Corregir error al hacer pitchbend en un canal distinto al 1
    [midiWindController.ino]
